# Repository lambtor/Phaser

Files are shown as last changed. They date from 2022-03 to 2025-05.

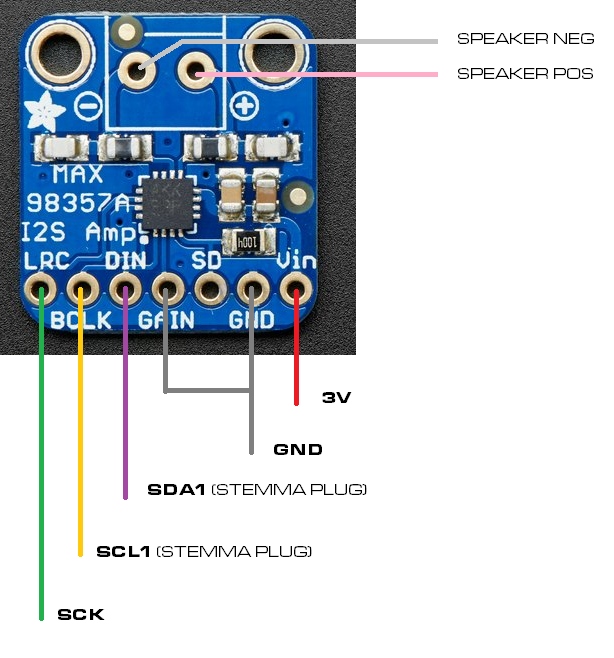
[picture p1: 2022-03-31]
t1 max98357 pinout.jpg

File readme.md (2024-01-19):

Purpose of this project is to code a phaser prop from star trek TNG / DS9 / VOY / LD.<br>
This will try to support both the 2 row, 16 intensity setting type 2 phaser and the 1 row, 8 intensity setting type 1.<br>
This is coded in circuitpython and meant to be run on an adafruit rp2040 propmaker board with a custom PCB attached. Settings and beam neopixels, buttons used will be on a custom designed PCB.
<br><br>
<strong>Project scope / intended features:</strong><br>
<ol>
	<li>
3 buttons: 2 for settings and 1 main trigger</li>
<li>firing sound mapped to button press. keep firing sound playing in loop while trigger held down.  need 2 sound files to do this, with warmup sound separate from active firing.  active firing sound must be loopable.</li>
<li>have setting buttons cause setting change sound to play</li>
<li>2 chains of neopixels: 1 for settings and 1 for beam</li>
<li>have neopixels for beam flicker slightly during firing</li>
<li>display current battery level in setting neopixel row when battery is charging - animated blue?</li>
<li>support a "warning shot" mode, where a single white led is lit in setting bar, and firing in this mode has beam at its dimmest with sound at its loudest</li>
<li>for type 2 (16 setting leds), have settings 1-8 light only 1 row from left to right as all green. for settings 9-16, light top row red while also fading bottom row from green to orange.<br>
	for type 1 (8 setting leds), have settings 1-8 fade from green (at 1) to red (at 8).</li>
<li>ability to set phaser to overload - hold down setting increase button for 3 seconds while setting is already at maximum. play "overload" sound and have all setting LEDs flashing red at a gradually increasing rate over 10 seconds before playing an "overload explosion" sound. after overload routine finishes, set phaser to sleep mode.</li>
<li>ability to activate wesley crusher's "autofire" mode - hold setting decrease button for 3 seconds.  this mode, when active, should have current intensity setting leds flash. this mode should be deactivated when either setting button has been pressed, and setting leds should return to solid on to reflect that.</li>
<li>sleep mode. when no buttons on the phaser have been pressed for a certain amount of time (2 minutes - this is a constant defined at the top of the code), all lights turn off and power use is minimized until a button has been pressed to wake again.</li>
</ol><br>
potential functions:<br>
"grime washing mode"?  not sure what this would be, or how it could be displayed in settings bar. maybe this is the same as "warning shot".<br>
<strike>method of changing phaser from "left handed" to "right handed" mode.  this would change how setting buttons behave and order of setting led pattern.</strike> this has been canceled in favor of enable/disable sleep mode toggle in menu.<br>
<br>
potential non-canon settings: (need to figure out if these should persist between full powercycles)<br>
beam brightness - including an "off" option, if anybody uses this for filming and wanted to add beam in post prod?<br>
setting led row brightness<br>
sound effect volume level<br>
reset all settings to default<br>
<br>References:<br>
https://learn.adafruit.com/mp3-playback-rp2040
<br>
<br>
To-do:
<ul>
<li>
modify flicker behavior to instead randomly set 2 beam chain pixel colors
</li>
<li>
flash battery level when setting down button is held for 2s and intensity already at minimum (in Mariner mode)
</li>
</ul>

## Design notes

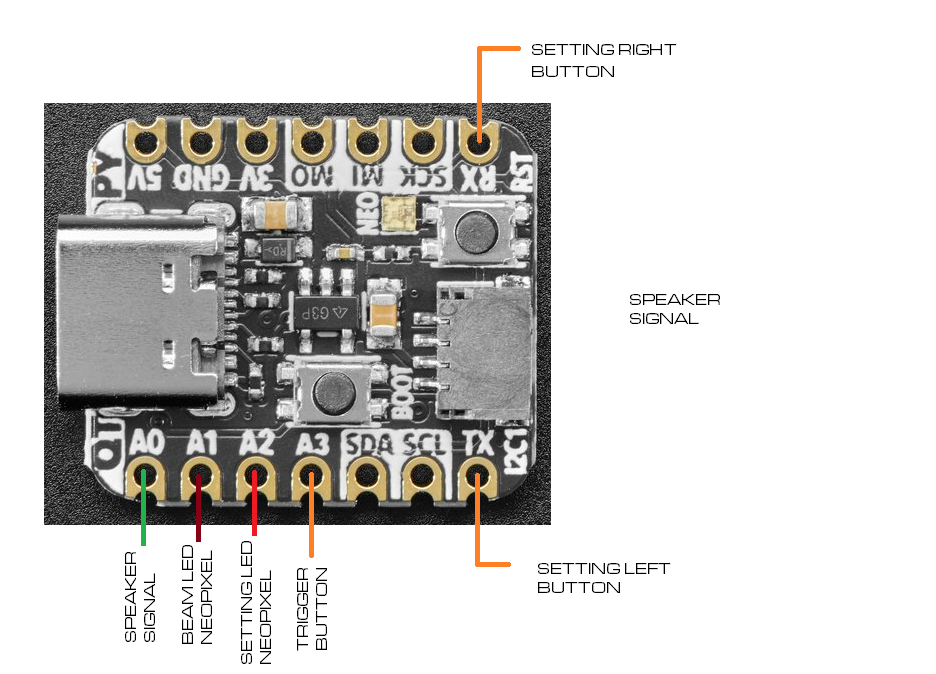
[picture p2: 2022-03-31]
t1 phaser pinout.png

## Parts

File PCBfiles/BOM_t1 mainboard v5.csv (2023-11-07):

ID | Name | Designator | Footprint | Quantity | Manufacturer Part | Manufacturer | Supplier | Supplier Part | Price
1 | LED-SMD_4P-L2.0-W2.0-BR | U1,U9,U6,U5,U10,U11,U12,U13 | LED-SMD_4P-L2.0-W2.0-BR | 8 | SK6812-EC20 | 欧思科光电 | LCSC | C2909058 | 0.204
2 | LED-SMD_WS2812B-4020 | U3,U4,U1,U2 | LED-SMD_WS2812B-4020 | 4 | WS2812B-4020 | worldsemi | LCSC | C965557 | 0.103
3 | SW-SMD_K3-1203S-E1 | U7 | SW-SMD_K3-1203S-E1 | 1 | K3-1203S-E1 | 韩国韩荣 | LCSC | C92661 | 0.552
4 | R0603 | R2,R1 | R0603 | 2 | WR06X1003FTL | Walsin(华新科) | LCSC | C132374 | 0.001
5 | KEY-SMD_4P-L5.2-W5.2-P3.70-LS6.4 | KEY0,KEY2,KEY1 | KEY-SMD_4P-L5.2-W5.2-P3.70-LS6.4 | 3 | K2-1187SQ-B4SW | HRO | LCSC | C108650 | 0.066
6 | LED-SMD_4P-L2.0-W2.0-TL_WS2812B-2020 | LED16,LED15,LED14,LED13,LED12,LED11,LED10,LED9 | LED-SMD_4P-L2.0-W2.0-TL_WS2812B-2020 | 8 | WS2812B-2020 | Worldsemi | LCSC | C965555 | 0.1

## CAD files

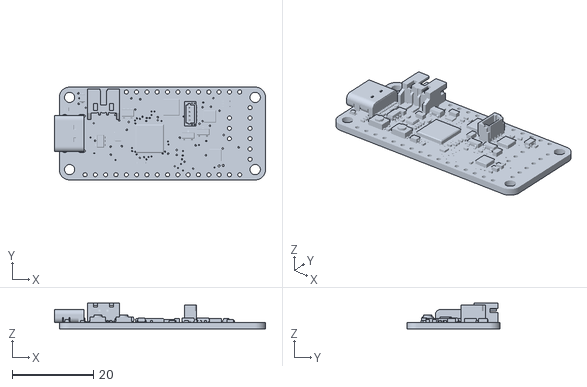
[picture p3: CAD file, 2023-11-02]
PCBfiles/RP2040 PropMakerSlim.stl
52.0 x 22.9 x 6.37

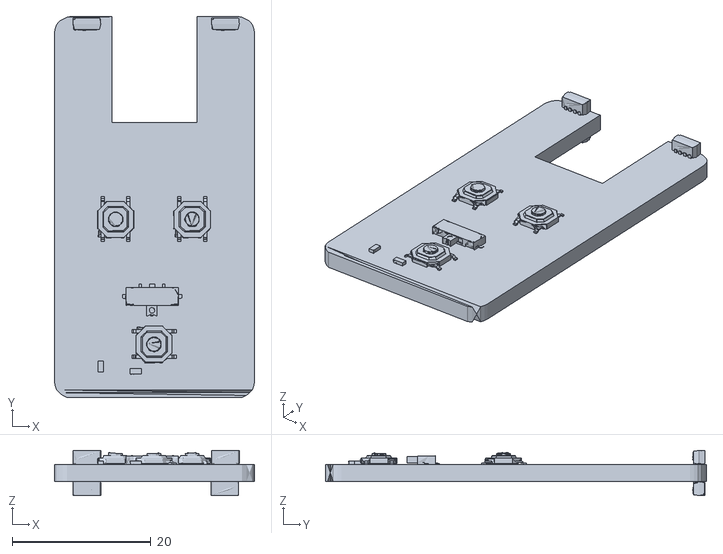
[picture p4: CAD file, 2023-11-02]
PCBfiles/customPCB.stl
28.9 x 55.0 x 6.50

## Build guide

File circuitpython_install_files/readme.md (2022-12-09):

This directory contains circuitpython install files for supported boards.  
v0.10-alpha should have v7.3.3 of the circuitpython install - latest stable.
<br><br>
Always install the circuitpython uf2 file before copying any phaser code.

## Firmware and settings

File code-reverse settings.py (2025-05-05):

import board
import digitalio
import neopixel
# import audioio
import audiocore
# from audiocore import WaveFile
from adafruit_debouncer import Debouncer
import time
import random
import math
from userSettings import UserSettings
from menuOptions import MenuOptions
import alarm
# this script is meant to be used with qt py rp2040
# this is for MAX98357A speaker board. drop wav files in main directory of qt py board
import audiobusio
import audiomixer
from analogio import AnalogIn

# OK OMFG mu editor has a max of 88 characters per line of code
# ---------------------------------------------------------------------------------------
# User config settings - these should be set once for program
# to behave for your hardware
# true or false here. False means program is for a type 2
# A3 is for laser itself. TX might need to be used for beam neopixels.
IS_TYPE_ONE_PHASER = True
SETTING_LED_PIN = board.A2
BEAM_LED_PIN = board.TX
BATTERY_PIN = board.A0
BEAM_LASER_PIN = board.A3
# if using stemma speaker board, this MIGHT use pin SDA1?
# only 3 pins connected when using stemma speaker board, so maybez
SETTING_SND_FILE = "adjust.wav"
FIRELOOP_SND_FILE = "firingloop.wav"
FIREWARM_SND_FILE = "warmup.wav"
FIREDOWN_SND_FILE = "cooldown.wav"
OVERLOAD_SND_FILE = "overload.wav"
EXPLOSION_SND_FILE = "explosion.wav"
# 0 here is simple blink of highest level LED with rest solid
# 1 is a "wave" that flows left-right
CHARGING_STYLE = 0
BTN_LEFT = board.MOSI
BTN_RIGHT = board.MISO
BTN_TRIGGER = board.RX
# menu settings. 8 total LEDs, so if you want these re-ordered,
# set their places here. ALL these need to be unique integers < 8
MENUIDX_FREQ = 0
MENUIDX_AUTO = 1
MENUIDX_VOL = 2
MENUIDX_SLEEP = 3
MENUIDX_STG = 4
MENUIDX_BEAM = 5
MENUIDX_OVLD = 6
MENUIDX_EXIT = 7

# number from 0-1 (you'd never want 1, as that'd be ALWAYS OFF
BEAM_FLICKER_RATE = 0.1
BEAM_FPS = 90

# --------
# current active device settings - do these need to persist across power cycles?

mnIntensitySetting = 0
# this needs to be 1 more than the total number of actual setting LEDs you have
if IS_TYPE_ONE_PHASER:
    mnSettingLEDMax = 9
else:
    mnSettingLEDMax = 17
mnBeamLEDCount = 8

# try:
#    from audioio import AudioOut
# except ImportError:
#    try:
#        from audiopwmio import PWMAudioOut as AudioOut
#    except ImportError:
#        pass
moI2SAudio = audiobusio.I2SOut(board.SDA, board.SCL, board.SCK)

moSettingSoundFile = open(SETTING_SND_FILE, "rb")
moFiringLoopFile = open(FIRELOOP_SND_FILE, "rb")
moFireWarmFile = open(FIREWARM_SND_FILE, "rb")
moFireDownFile = open(FIREDOWN_SND_FILE, "rb")
moExplosionFile = open(EXPLOSION_SND_FILE, "rb")
moOverloadFile = open(OVERLOAD_SND_FILE, "rb")
moSettingSnd = audiocore.WaveFile(moSettingSoundFile)
moFireLoopSnd = audiocore.WaveFile(moFiringLoopFile)
moFireWarmSnd = audiocore.WaveFile(moFireWarmFile)
moFireDownSnd = audiocore.WaveFile(moFireDownFile)
moOverloadSnd = audiocore.WaveFile(moOverloadFile)
moExplosionSnd = audiocore.WaveFile(moExplosionFile)
mnFireWarmSndLength = 1.25
mnOvldSndLength = 0.2
mdFireLEDLength = 0.18
mnFireWarmStep = 0

moRGBRed = (255, 0, 0)
moRGBFullRed = (255, 0, 0)
moRGBBlack = (0, 0, 0)
moRGBWarn = (128, 0, 128)
moRGBStrength = 128
moRGBBattery = (0, 0, 255)
moUser = UserSettings()

# set values here to persist between "sleep" periods
# check if alarm is none
if (alarm.wake_alarm is not None):
    # pull these values from sleep_memory
    if (alarm.sleep_memory is True):
        print("loading settings from sleep memory")
        moUser.Frequency = alarm.sleep_memory[MENUIDX_FREQ]
        moUser.Volume = alarm.sleep_memory[MENUIDX_VOL]
        moUser.BeamBrightIndex = alarm.sleep_memory[MENUIDX_BEAM]
        moUser.SettingBrightIndex = alarm.sleep_memory[MENUIDX_STG]

# user settings required for mixer definition of volume. all wav files are 22050 sample rate.
# if you use a different sample rate, use same one for all sound files and specify it here
moMixer = audiomixer.Mixer(voice_count=1, sample_rate=22050, channel_count=1, bits_per_sample=16, samples_signed=True)

# all comments are done via pound sign,
# and MUST have a space immediately after the pound sign - this is some vb6 shit.
# gtfo with your variable types! this is PYTHON! everything's interpolated!
# long-term: left handed mode that can be toggled on/off via both setting button press?
# mpinBoardLed = digitalio.DigitalInOut(board.LED)
# board.BUTTON
mpinBoardLed = neopixel.NeoPixel(board.NEOPIXEL, 1, brightness=0.3, auto_write=True)
# mpinBoardLed = neopixel.NeoPixel(board.NEOPIXEL, 1)
# mpinBoardLed.brightness = 0.3
mpinBoardLed.fill((112, 128, 0))
mpinBoardLed.write()

moLaser = digitalio.DigitalInOut(BEAM_LASER_PIN)
moLaser.direction = digitalio.Direction.OUTPUT

# 6-8 status leds in a single row, or 16 split across 2 rows
# setting lowest value is 0, max is count of setting LEDs?
moSettingRow = neopixel.NeoPixel(SETTING_LED_PIN, mnSettingLEDMax - 1)
moSettingRow.brightness = 0.1
moSettingRow.auto_write = False

# a laser pointer driven by 5v, with 1 neopixel on each side.
# these are going to be mounted on a custom pcb with a hole to fit pointer
moBeamRow = neopixel.NeoPixel(BEAM_LED_PIN, mnBeamLEDCount)
moBeamRow.brightness = 0.5
moBeamRow.auto_write = False

# pin alarms. 3 separate ones to allow any button press to wake phaser
moPinAlarmL = alarm.pin.PinAlarm(BTN_LEFT, value=False, pull=True)
moPinAlarmR = alarm.pin.PinAlarm(BTN_RIGHT, value=False, pull=True)
moPinAlarmT = alarm.pin.PinAlarm(BTN_TRIGGER, value=False, pull=True)

# time function returns everything as seconds.
# all comparisons for delay less than 1 second need to use decimals
mbIsFiring = False
mbIsWarming = False
mnChargingFrame = 0
mdecChargingFrameDelay = 0.25
mnChargingLastTime = 0
mnLastBattCheck = 0
mnBattCheckInterval = 1
mdFiringLastTime = 0
mnWarmLastTime = 0
mdecStartFiringTime = 0.0
mdecLastBeamFrame = 0.0
# this is used in main loop to control button behavior
# 0 = normal, 1 = menu, 2 = charging
# 3 = autofire, 4 = overload
moActiveMode = 0
mdecModeTime = 0.0
mdecBtnTime = time.monotonic()
mdecSleepMax = 120
# seconds between check for current active mode
mnModeInterval = 1
mnMenuModeThreshold = 2.0
mbMenuBtn1Clear = False
mbMenuBtn2Clear = False
mnMenuIndex = 0
mdecMenuFlashDelay = 0.3
mdecMenuLastFlash = 0.0
mbMenuIndexLEDOff = True
mdecOverFrameDelay = 0.5
mnMaxOverFrame = 60
mnCurrOverFrame = 0
mnOverFrameSpeed = 0.3
mnOverFrameSpDef = 0.3
mdecOverMult = 1.25
mdecOverLastTime = 0
mdecAutoCoolTime = 0.0
mbAutoCooldown = False
mbAutoFlashing = False
mdecAutoFlashTime = 0.0
mdecAutoFlashDelay = 0.25
mdecAutoStart = 0.0
mdecAutoBeamStart = 0.0
mdecAutoBeamEnd = 0.0
moBatteryRead = AnalogIn(BATTERY_PIN)
mbBatteryShown = False

def ButtonRead(pin):
    io = digitalio.DigitalInOut(pin)
    io.direction = digitalio.Direction.INPUT
    io.pull = digitalio.Pull.UP
    return lambda: io.value

def SettingDecrease(nAmount):
    global mnIntensitySetting
    if mnIntensitySetting > 0:
        mnIntensitySetting -= nAmount
    UpdateIntensity()

def SettingIncrease(nAmount):
    global mnSettingLEDMax
    global mnIntensitySetting
    if mnIntensitySetting < (mnSettingLEDMax - 1):
        mnIntensitySetting += nAmount
    UpdateIntensity()

# settings with 2 bars, bottom bar goes unlit to full green
# then from full green, for 8-15, this bar fades green to orange
# while top bar climbs up red. at 15, bottom bar is full orange
# and top bar is full red.
# need way to set phaser to overload from setting 15 (hold up btn 5 sec?)
# need way to set phaser to autofire (wesley) from zero (hold down btn 3 sec?)
# warning shot mode, set 1 LED pink & max sound min beam brightness
def UpdateIntensity():
    global mnIntensitySetting
    global moSettingRow
    global moRGBRed
    global moRGBBlack
    global moRGBStrength
    global mnSettingLEDMax
    global IS_TYPE_ONE_PHASER
    nIndxSettingMax = mnSettingLEDMax - 2
    nReversedPolarity = 0

    # print(mnIntensitySetting)
    if mnIntensitySetting == 0:
        # moSettingRow.fill(moRGBBlack)
        # moSettingRow.write()
        WarningShotMode()
        return

    # to-do: flip orientation
    # canon behavior for settings with 8 leds
    if (IS_TYPE_ONE_PHASER is True):
        # transition entire row from green to red as it marches from 0-7
        for nIterator2 in range(mnSettingLEDMax - 1):
            # 0 128 0 to 128 0 0
            if nIterator2 < mnIntensitySetting:
                nRed = int((mnIntensitySetting - 1) * 16)
                nGreen = 128 - nRed
                # use nIterator2 instead for settings row leds that are aligned correctly
                # moSettingRow[nIterator2] = (nRed, nGreen, 0)
                # this is for LEDs wired in the wrong direction, 7-0 instead of 0-7
                nReversedPolarity = nIndxSettingMax - nIterator2
                moSettingRow[nReversedPolarity] = (nRed, nGreen, 0)
            else:
                # use nIterator2 instead for settings row leds that are aligned correctly
                nReversedPolarity = nIndxSettingMax - nIterator2
                # moSettingRow[nIterator2] = moRGBBlack
                moSettingRow[nReversedPolarity] = moRGBBlack
    else:
        # this will be 0 to number of setting LEDs - 1
        for nIterator in range(mnSettingLEDMax - 1):
            if nIterator > 7:
                if mnIntensitySetting >= 8:
                    if mnIntensitySetting > nIterator:
                        moSettingRow[nIterator] = moRGBRed
                    else:
                        moSettingRow[nIterator] = moRGBBlack
            else:
                if mnIntensitySetting > 8:
                    # if mnIntensitySetting >= nIterator:
                    nRed = int((mnIntensitySetting - 7) * 16)
                    nGreen = int(moRGBStrength - (8 * (mnIntensitySetting - 7)))
                    moSettingRow[nIterator] = (nRed, nGreen, 0)
                else:
                    if nIterator < mnIntensitySetting:
                        # set any LED at or below current setting as green
                        moSettingRow[nIterator] = (0, moRGBStrength, 0)
                    else:
                        moSettingRow[nIterator] = moRGBBlack
    moSettingRow.write()
    # set intensity according to user-selected max brightness
    # update beam brightness to reflect intensity setting
    # moBeamRow.brightness = (1 / (mnSettingLEDMax - mnIntensitySetting))
    decBeamLvBright = (1 / (mnSettingLEDMax - mnIntensitySetting))
    moBeamRow.brightness = decBeamLvBright * GetBeamBrightnessLevel()
    # moBeamRow.brightness = GetBeamBrightnessLevel()
    moBeamRow.write()

def WarningShotMode():
    global moSettingRow
    global moRGBBlack
    global moRGBWarn
    global mnSettingLEDMax
    nIndxSettingMax = mnSettingLEDMax - 2
    # this is for reversed LEDS - set 7 as pink instead of 0
    moSettingRow.fill(moRGBBlack)
    moSettingRow[nIndxSettingMax] = moRGBWarn
    moSettingRow.write()

def DisableWarningShotMode():
    global moSettingRow
    moSettingRow.fill(moRGBBlack)
    moSettingRow.write()

def StartFiring(bIsInit):
    global mbIsFiring
    global moBeamRow
    global mbIsWarming
    global mnFireWarmStep
    global mnWarmLastTime
    global mnFireWarmSndLength
    global mdecStartFiringTime
    global moUser
    global moRGBBlack
    global moRGBRed
    nFadeSteps = 4

    # need to fade in beam WAY faster than warmup sound
    if not mbIsWarming and not bIsInit:
        return
    if bIsInit is True:
        mbIsWarming = True
    # kick out if it's too soon to step to next frame
    if (time.monotonic() - mnWarmLastTime) < (mdFireLEDLength / nFadeSteps):
        return

    # oColor = MenuOptions.Frequency[moUser.Frequency]
    oColor = moRGBRed
    oColorAlt = MenuOptions.FreqSup[moUser.Frequency]
    oFreqR = oColor[0]
    oFreqG = oColor[1]
    oFreqB = oColor[2]

    # fade from black up to full red - this is non-blocking
    if (mnFireWarmStep < nFadeSteps):
        oFreqR = int(oColor[0] / (nFadeSteps - mnFireWarmStep))
        oFreqB = int(oColor[1] / (nFadeSteps - mnFireWarmStep))
        oFreqG = int(oColor[2] / (nFadeSteps - mnFireWarmStep))
        oColor = (oFreqR, oFreqG, oFreqB)
        moBeamRow.fill(oColor)
        moBeamRow.write()
        mnWarmLastTime = time.monotonic()
        # print(mnFireWarmStep, " | ", oColor)
        mnFireWarmStep += 1
        return
    # flicker during warmup
    if ((time.monotonic() - mnWarmLastTime) >= (1 / BEAM_FPS)):
        nRand = random.randint(0, 9)
        # nRand = int(math.modf(time.monotonic())[0] * 10)
        if (nRand < (BEAM_FLICKER_RATE * 10)):
            moBeamRow.fill(oColorAlt)
            moBeamRow.show()
            moLaser.value = False
        else:
            moLaser.value = True
            moBeamRow.fill(oColor)
            moBeamRow.show()
        mnWarmLastTime = time.monotonic()
    decTimeRef = time.monotonic() - mdecStartFiringTime
    # warming over, set isFiring flag on to hand over to that animation
    if mnFireWarmStep >= nFadeSteps and (decTimeRef > mnFireWarmSndLength):
        mbIsWarming = False
        mnFireWarmStep = 0
        mbIsFiring = True
        RunFiring(True)

def RunFiring(bInitLoop):
    global mbIsFiring
    global BEAM_FPS
    global BEAM_FLICKER_RATE
    global moI2SAudio
    global moBeamRow
    global moRGBBlack
    global moRGBRed
    global mnBeamLEDCount
    global mdFiringLastTime
    global moUser
    global moLaser
    if (bInitLoop is True):
        mbIsFiring = True
        # moI2SAudio.play(moFireLoopSnd, loop=True)
        PlaySound(moFireLoopSnd, False, True)
    # depending on "refresh rate" and "flicker rate" values at top,
    # occasionally turn off beam neopixels uniformly?
    # if (not mbIsFiring and not bInitLoop) or mbInMenu is True or mbIsCharging is True:
    if (not mbIsFiring and not bInitLoop):
        return
    if ((time.monotonic() - mdFiringLastTime) >= (1 / BEAM_FPS)):
        nRand = random.randint(0, 9)
        # nRand = int(math.modf(time.monotonic())[0] * 10)
        if (nRand < (BEAM_FLICKER_RATE * 10)):
            # moBeamRow.fill(moRGBBlack)
            moBeamRow.fill(MenuOptions.FreqSup[moUser.Frequency])
            moBeamRow.show()
            moLaser.value = False
        else:
            # moBeamRow.fill(MenuOptions.Frequency[moUser.Frequency])
            moBeamRow.fill(moRGBRed)
            moBeamRow.show()
            moLaser.value = True
        mdFiringLastTime = time.monotonic()

def StopFiring():
    global moBeamRow
    global mbIsFiring
    global mbIsWarming
    global moI2SAudio
    global mnFireWarmStep
    global moFireDownSnd
    global moLaser
    # run cooldown sound
    # moI2SAudio.stop()
    # moI2SAudio.play(moFireDownSnd, loop=False)
    PlaySound(moFireDownSnd)
    # block on cooldown sound
    # while moI2SAudio.playing:
    #    pass
    # moBeamRow.fill(moRGBBlack)
    # moBeamRow.show()
    mnFireWarmStep = 0
    if (mbIsWarming is True):
        time.sleep(0.2)
    else:
        time.sleep(0.1)
    mbIsFiring = False
    mbIsWarming = False
    moBeamRow.fill(moRGBBlack)
    moBeamRow.show()
    moLaser.value = False

def StartOverload():
    global moActiveMode
    global moSettingRow
    global moRGBRed
    global mnOverFrameSpeed
    moSettingRow.fill(moRGBRed)
    moSettingRow.show()
    time.sleep(3)
    moActiveMode = 4
    # play overload warmup sound non-blocking
    # pass

def RunOverload():
    global moSettingRow
    global moRGBRed
    global moRGBBlack
    global mnOverFrameSpeed
    global mdecOverLastTime
    global mdecOverMult
    global mnMaxOverFrame
    global mnOverFrameSpDef
    global moPinAlarmL
    global moPinAlarmR
    global moPinAlarmT
    global mnCurrOverFrame
    global moOverloadSnd
    global moExplosionSnd
    global mnOvldSndLength

    # global moActiveMode
    # need to flash all setting LEDs progressively faster
    # while warmup sound plays - track this with frame #
    nNow = time.monotonic()
    if ((nNow - mdecOverLastTime > mnOverFrameSpeed) and (mnCurrOverFrame <= mnMaxOverFrame)):
        if (mnCurrOverFrame % 2 == 0):
            moSettingRow.fill(moRGBRed)
            # play beep if frame speed is slower than length of beep sound file
            # if (mnOverFrameSpeed > mnOvldSndLength):
            PlaySound(moOverloadSnd, False, False, False)
        else:
            moSettingRow.fill(moRGBBlack)
        if (mnCurrOverFrame % 8 == 0):
            mnOverFrameSpeed = mnOverFrameSpeed / mdecOverMult
        mnCurrOverFrame += 1
        moSettingRow.write()
        mdecOverLastTime = nNow
        # print(mnCurrOverFrame)
    elif (mnCurrOverFrame > mnMaxOverFrame):
        # to-do:
        # play explosion sound
        moSettingRow.fill(moRGBRed)
        moSettingRow.write()
        time.sleep(0.2)
        mnCurrOverFrame = 0
        mnOverFrameSpeed = mnOverFrameSpDef
        mdecOverLastTime = nNow
        moSettingRow.fill(moRGBBlack)
        moSettingRow.write()
        time.sleep(0.2)
        # wait for sound to finish playing before sending board to sleep
        PlaySound(moExplosionSnd, True, False, True)
        # go to sleep mode
        alarm.exit_and_deep_sleep_until_alarms(moPinAlarmL, moPinAlarmR, moPinAlarmT)

def StopOverload():
    global moActiveMode
    global moSettingRow
    moActiveMode = 0
    moSettingRow.fill(moRGBBlack)
    moSettingRow.show()
    time.sleep(0.2)
    # play wind-down sound?
    UpdateIntensity()

def StartAutofire():
    global moActiveMode
    global moSettingRow
    global mbAutoCooldown
    global mdecAutoCoolTime
    global mdecAutoFlashDelay
    moActiveMode = 3
    UpdateIntensity()
    mbAutoCooldown = True
    # set autofire cooldown timestamp as NOW
    mdecAutoCoolTime = time.monotonic()
    # print("cooldown start " + str(mdecAutoCoolTime))
    # time.sleep(mdecAutoFlashDelay * 2)

def RunAutofire():
    global mbIsWarming
    global mdecAutoCoolTime
    global mbAutoCooldown
    global mdecAutoStart
    # global mdecAutoBeamStart
    global mdecStartFiringTime
    global mdecAutoBeamEnd
    global mdecAutoFlashTime
    global mdecAutoFlashDelay
    global mbAutoFlashing
    global moSettingRow
    global moI2sAudio
    global moFireWarmSnd

    # need to animate settings to convey autofire
    # use current intensity as periodically flashing
    dtNow = time.monotonic()
    if (dtNow - mdecAutoFlashTime > mdecAutoFlashDelay):
        if mbAutoFlashing is True:
            UpdateIntensity()
        else:
            moSettingRow.fill(moRGBBlack)
            moSettingRow.show()
        mbAutoFlashing = not mbAutoFlashing
        mdecAutoFlashTime = time.monotonic()

    if mbAutoCooldown is True:
        if (time.monotonic() - mdecAutoCoolTime > 5):
            mbAutoCooldown = False
            # mdecAutoBeamStart = time.monotonic()
            # mdecStartFiringTime = mdecAutoBeamStart
            mdecStartFiringTime = time.monotonic()
            # moI2SAudio.play(moFireWarmSnd)
            PlaySound(moFireWarmSnd)
            # print("start firing " + str(mdecStartFiringTime))
            StartFiring(True)
    else:
        if mbIsWarming is True:
            # print("warming " + str(time.monotonic()))
            StartFiring(False)
        else:
            RunFiring(False)
        if (dtNow - mdecStartFiringTime >= 3):
            StopFiring()
            mdecAutoCoolTime = time.monotonic()
            mbAutoCooldown = True

def StopAutofire():
    global moActiveMode
    global moSettingRow
    moActiveMode = 0
    moSettingRow.fill(moRGBBlack)
    moSettingRow.show()
    time.sleep(0.3)
    # play cancel sound?
    UpdateIntensity()

def CheckCharging():
    # if charging mode is active, run charging mode
    global moActiveMode
    # moBatteryRead
    # voltage over threshold means connected to usb
    # anytime usb connected, battery is charging
    # if (voltage > maximum)
    # moActiveMode = 2
    # set brightness for settings chain to 0.4
    # to allow brightness for animation
    # if (moSettingRow.brightness != GetSettingBrightnessLevel()):
    #    moSettingRow.brightness = GetSettingBrightnessLevel()
    # change mode to normal and update setting row
    # elif (moActiveMode == 2)
    # moActiveMode = 0
    # DisableCharging()
    pass

def ShowBattery():
    global moSettingRow
    global moRGBBlack
    global moRGBBattery
    blinkLength = 0.4
    blinkCount = 10
    # print(GetVoltage())
    decCurrentVoltage = min(max(GetVoltage(), 3.2), 4.2)
    # print(decCurrentVoltage)
    nCurrentPower = int(map_range(decCurrentVoltage, 3.2, 4.2, 0.0, 8.0))
    print(nCurrentPower)
    bIsBlinking = False
    for nCount in range(blinkCount):
        if (not bIsBlinking):
            for nSettingLED in range(nCurrentPower):
                nPolarityPower = 7 - nSettingLED
                # use normal version if LEDs wired 0-7 left > right
                # moSettingRow[nSettingLED] = moRGBBattery
                moSettingRow[nPolarityPower] = moRGBBattery
        else:
            moSettingRow.fill(moRGBBlack)
        moSettingRow.write()
        time.sleep(blinkLength)
        bIsBlinking = not bIsBlinking

def GetVoltage():
    global moBatteryRead
    # this should be an approx 3.2 - 4.8
    # print((moBatteryRead.value * 6.6) / 65536)
    # apparently, previous versions used 3.3 as battery reference, but now this is 3.6
    # for this reason, if you use 3.3 with a newer version of firmware,
    # batt % will show 60 when it should be 100. 3.6 * 2 = 7.2
    return ((moBatteryRead.value * 7.2) / 65536)

def map_range(s, a1, a2, b1, b2):
    return math.ceil(b1 + ((s - a1) * (b2 - b1) / (a2 - a1)))

def DisableCharging():
    global moSettingRow
    global moRGBBlack
    moSettingRow.brightness = GetSettingBrightnessLevel()
    moSettingRow.fill(moRGBBlack)
    moSettingRow.show()
    UpdateIntensity()
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

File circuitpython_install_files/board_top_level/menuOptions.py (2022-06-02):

# all lists of options are arrays of RGB colors
class MenuOptions:
    Frequency = [(255, 0, 0), (255, 64, 0), (255, 128, 0), (255, 0, 64), (255, 0, 128), (255, 128, 128)]
    Autofire = (255, 48, 0)
    Volume = [(0, 255, 0), (0, 192, 0), (0, 128, 0), (0, 64, 0), (0, 32, 0), (32, 0, 0)]
    Orientation = [(255, 255, 0), (0, 0, 255)]
    SleepTimer = [(255, 255, 0), (0, 0, 255)]
    SettingBrightness = [(0, 0, 255), (0, 0, 204), (0, 0, 160), (0, 0, 96), (0, 0, 64), (0, 0, 32)]
    BeamBrightness = [(255, 0, 255), (204, 0, 204), (160, 0, 160), (96, 0, 96), (64, 0, 64), (32, 0, 32)]	
    Overload = (255, 0, 0)
    Exit = (160, 160, 160)
    # visible beam frequency should use the alternate color on "flicker"?
    # otherwise beam colors might look out of place?
    FreqSup = [(0, 0, 0), (0, 128, 0), (128, 128, 0), (0, 0, 128), (128, 0, 128), (0, 128, 128)]
    # 0, G, RG, B, RB, GB

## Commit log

2022-04-02 Update code.py
    added battery charging animation
2022-05-13 Add files via upload
    changed menu to only display current "highlighted" selection and "exit" options to minimize display complexity. settings row now uses menu-selected brightness setting.
2022-05-18 Add files via upload
    drastically reduced overload mode frame number for initial testing. will tune when future sound effect length is known
2022-05-19 Add files via upload
    play sound when button pressed to exit autofire or overload mode
2022-05-20 Add files via upload
    fixed some functions, added another lower brightness level for settings LEDs
    [code.py, menuOptions.py]
2022-05-20 Add files via upload
    idle timeout functionality fixed
    [code.py]
2022-05-26 Add files via upload
    fixed autofire not fully warming up. modified frequency changes to use red main beam with alternate colors on flicker even in autofire mode. current intensity setting flashes when autofire is running. need to determine cause of firing sound bleeding when autofire disabled.
    [code.py]
2022-06-06 Add files via upload
    disable sleep mode when phaser in autofire or charging
2022-08-04 Update code.py
    updated beam brightness for latest PCB
2022-08-11 Update code.py
    added logic to flash battery percentage on settings row every time phaser is woken from sleep mode. by hardware restrictions of BFF, cannot show "current" battery level while it is charging.
2022-08-11 Update code.py
    pressing down left setting button for 3 seconds then releasing it, while NOT in overload / autofire / menu will cause phaser to go to sleep
2022-08-12 Update code.py
    modified battery to use 3.6 multiplier, as full was showing at 60%
2022-10-18 Update code.py
    added A3 as laser pointer driver pin to flicker with beam neopixel leds.
2022-12-09 Add files via upload
    added setting to invert laser behavior when pcb assumes pulling low should turn it on. added beam flicker toggle to disable flicker to black when using default beam frequency
    [code.py]
2022-12-30 Update code.py
    max1704 support for battery level while connected to usb
2023-07-21 Create codePropMaker
    revised pinout for adafruit rp2040 propmaker board. do NOT use exposed d4 pin to drive neopixels, that is the pin used to drive the board-mounted one!
2023-07-21 Create codePropMaker.py
    don't use breakout pin d4 for neopixel chain - that is already in use for the board's neopixel.
2023-07-24 Update codePropMaker.py
    value for external power pin to actually enable ext neopixel and speaker
2023-10-24 Update codePropMaker.py
    battery charging logic - use a1 from vbat as analog input, enable charging display when input voltage over 4.2v
2023-10-24 Update codePropMaker.py
    per adafruit example, batt voltage is 3.6 * 2, not 3.3
2023-10-30 Update codePropMaker.py
    show battery level when hitting left button while at minimal intensity
2023-10-31 Update codePropMaker.py
    battery logic using raw value *2. percentage now shows full bar if battery at max
2023-11-02 Add files via upload
    reference 3d files for PCBs used in this build
    [RP2040 PropMakerSlim.stl, customPCB.stl]
2023-11-07 Add files via upload
    source .json project file for board design
2025-05-04 Add files via upload
    this is meant to handle if your settings neopixels from left-right are wired 7>0 instead of 0>7 order
2025-05-05 Add files via upload
    fixed "sleep memory unavailable" when attempting to save settings on a board with no memory
    [code-reverse settings.py]
